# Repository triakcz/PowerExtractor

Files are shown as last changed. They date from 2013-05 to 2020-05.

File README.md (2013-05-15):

PowerExtractor
==============

GPL MPPT Regulator for bike (development prototype)

This is not finished project in development. Using Arduino to maximize power extracted from dynamo hub or solar panels ... yes it is so universal. Prototype tests shown power output of 8Watts @ 40km/h. Conversion efficiency is about 90% measured after initial rectification).

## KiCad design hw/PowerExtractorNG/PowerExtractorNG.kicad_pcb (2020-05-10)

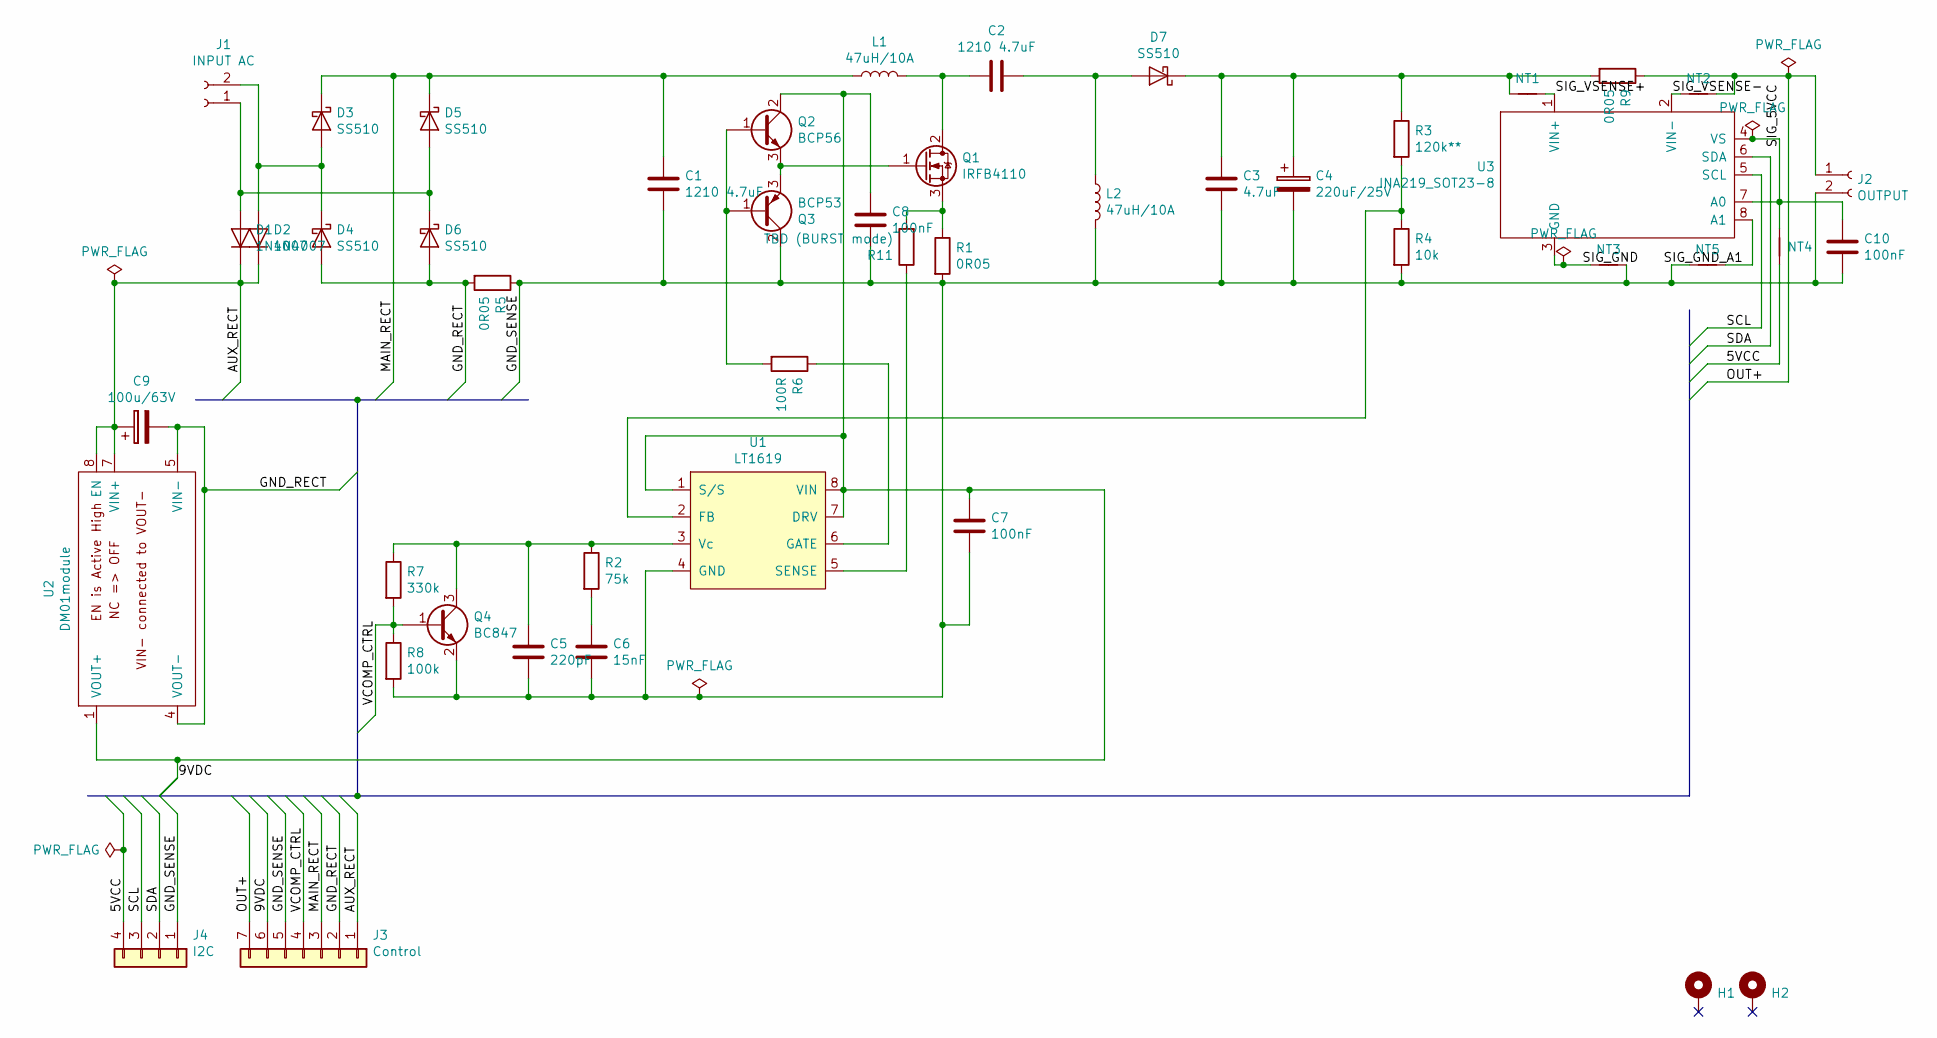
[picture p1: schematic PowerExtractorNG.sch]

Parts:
C1, C2: 1210 4.7uF; C_1210_3225Metric_Pad1.42x2.65mm_HandSolder
C3: 4.7uF; C_1210_3225Metric_Pad1.42x2.65mm_HandSolder
C4: 220uF/25V; CP_Radial_D10.0mm_P5.00mm
C5: 220pF; C_1206_3216Metric_Pad1.42x1.75mm_HandSolder
C6: 15nF; C_1206_3216Metric_Pad1.42x1.75mm_HandSolder
C7, C8, C10: 100nF; C_1206_3216Metric_Pad1.42x1.75mm_HandSolder
C9: 100u/63V; CP_Radial_D10.0mm_P5.00mm
D1, D2: 1N4007; D_SMA
D3, D4, D5, D6, D7: SS510; D_SMC_Handsoldering
H1, H2: MountingHole_Pad; MountingHole_3.2mm_M3_Pad
J1: INPUT AC; TerminalBlock_Altech_AK300-2_P5.00mm
J2: OUTPUT; TerminalBlock_Altech_AK300-2_P5.00mm
J3: Control; PinHeader_1x07_P2.54mm_Vertical
J4: I2C; PinHeader_1x04_P2.54mm_Vertical
L1, L2: 47uH/10A; L_Toroid_Vertical_L24.6mm_W15.5mm_P11.44mm_Pulse_KM-4
NT1, NT2, NT3, NT4, NT5: Net-Tie_2; NetTie-2_SMD_Pad0.5mm
Q1: IRFB4110; TO-220-3_Vertical
Q2: BCP56; SOT-223-3_TabPin2
Q3: BCP53; SOT-223-3_TabPin2
Q4: BC847; SOT-23
R1, R5, R9: 0R05; R_2512_6332Metric_Pad1.52x3.35mm_HandSolder
R2: 75k; R_1206_3216Metric_Pad1.42x1.75mm_HandSolder
R3: 120k**; R_1206_3216Metric_Pad1.42x1.75mm_HandSolder
R4: 10k; R_1206_3216Metric_Pad1.42x1.75mm_HandSolder
R6: 100R; R_1206_3216Metric_Pad1.42x1.75mm_HandSolder
R7: 330k; R_1206_3216Metric_Pad1.42x1.75mm_HandSolder
R8: 100k; R_1206_3216Metric_Pad1.42x1.75mm_HandSolder
R11: TBD (BURST mode); R_1206_3216Metric_Pad1.42x1.75mm_HandSolder
U1: LT1619; SO-8_5.3x6.2mm_P1.27mm
U2: DM01module; DM01_mod_THT
U3: INA219_SOT23-8; SOT-23-8_Handsoldering

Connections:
/5VCC: J4.4, NT4.2
/9VDC: C7.1, C8.1, J3.6, Q2.2 (C), U1.1 (S/S), U1.7 (DRV), U1.8 (VIN), U2.1 (VOUT+)
/AUX_RECT: C9.1, D1.1 (K), D2.1 (K), J3.1, U2.7 (VIN+), U2.8 (EN)
/GND_RECT: C9.2, D4.2 (A), D6.2 (A), J3.2, R5.2, U2.4 (VOUT-), U2.5 (VIN-)
/GND_SENSE: C1.2, C3.2, C4.2, C5.2, C6.2, C7.2, C8.2, C10.2, J2.2, J3.5, J4.1, L2.2, NT3.2, NT5.1, Q3.2 (C), Q4.2 (E), R1.2, R4.2, R5.1, R8.2, U1.4 (GND)
/MAIN_RECT: C1.1, D3.1 (K), D5.1 (K), J3.3, L1.1
/OUT+: J2.1, J3.7, NT2.2, R9.1
/SCL: J4.3, U3.5 (SCL)
/SDA: J4.2, U3.6 (SDA)
/SIG_5VCC: C10.1, NT4.1, U3.4 (VS), U3.7 (A0)
/SIG_GND: NT3.1, U3.3 (GND)
/SIG_GND_A1: NT5.2, U3.8 (A1)
/SIG_VSENSE+: NT1.2, U3.1 (VIN+)
/SIG_VSENSE-: NT2.1, U3.2 (VIN-)
/VCOMP_CTRL: J3.4, Q4.1 (B), R7.2, R8.1
unnamed: C2.1, D7.2 (A), L2.1
unnamed: C2.2, L1.2, Q1.2 (D)
unnamed: C3.1, C4.1, D7.1 (K), NT1.1, R3.1, R9.2
unnamed: C5.1, Q4.3 (C), R2.1, R7.1, U1.3 (Vc)
unnamed: C6.1, R2.2
unnamed: D1.2 (A), D5.2 (A), D6.1 (K), J1.1
unnamed: D2.2 (A), D3.2 (A), D4.1 (K), J1.2
unnamed: Q1.1 (G), Q2.3 (E), Q3.3 (E)
unnamed: Q1.3 (S), R1.1, R11.2
unnamed: Q2.1 (B), Q3.1 (B), R6.2
unnamed: R3.2, R4.1, U1.2 (FB)
unnamed: R6.1, U1.6 (GATE)
unnamed: R11.1, U1.5 (SENSE)

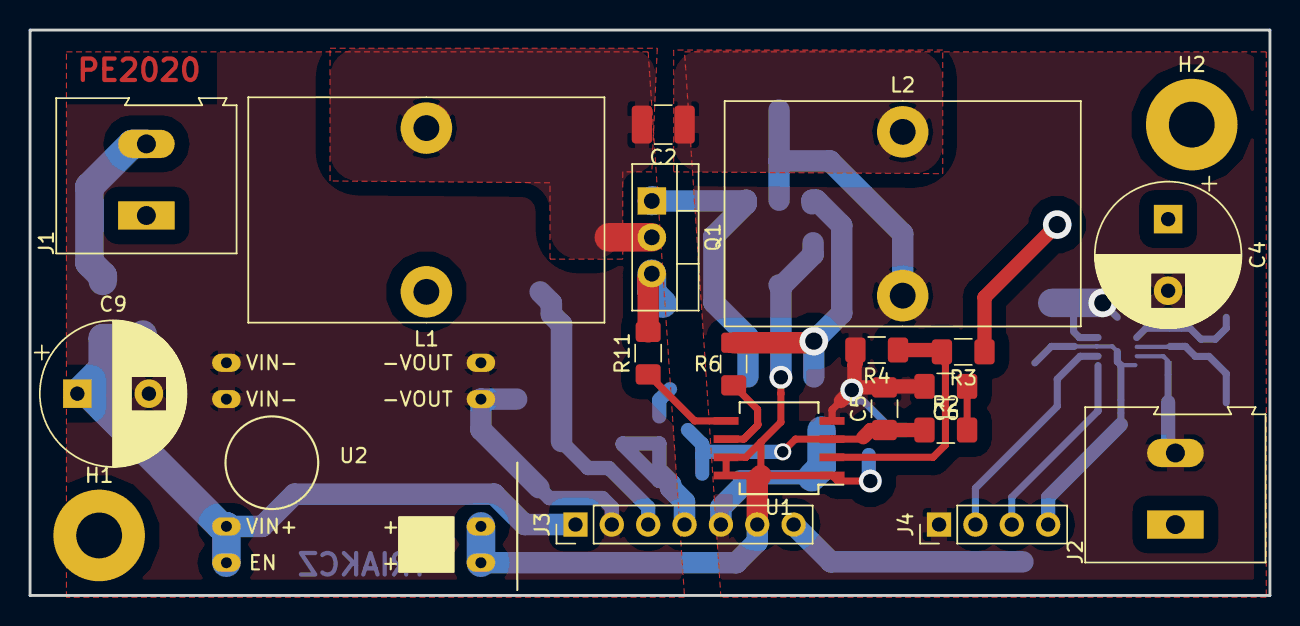
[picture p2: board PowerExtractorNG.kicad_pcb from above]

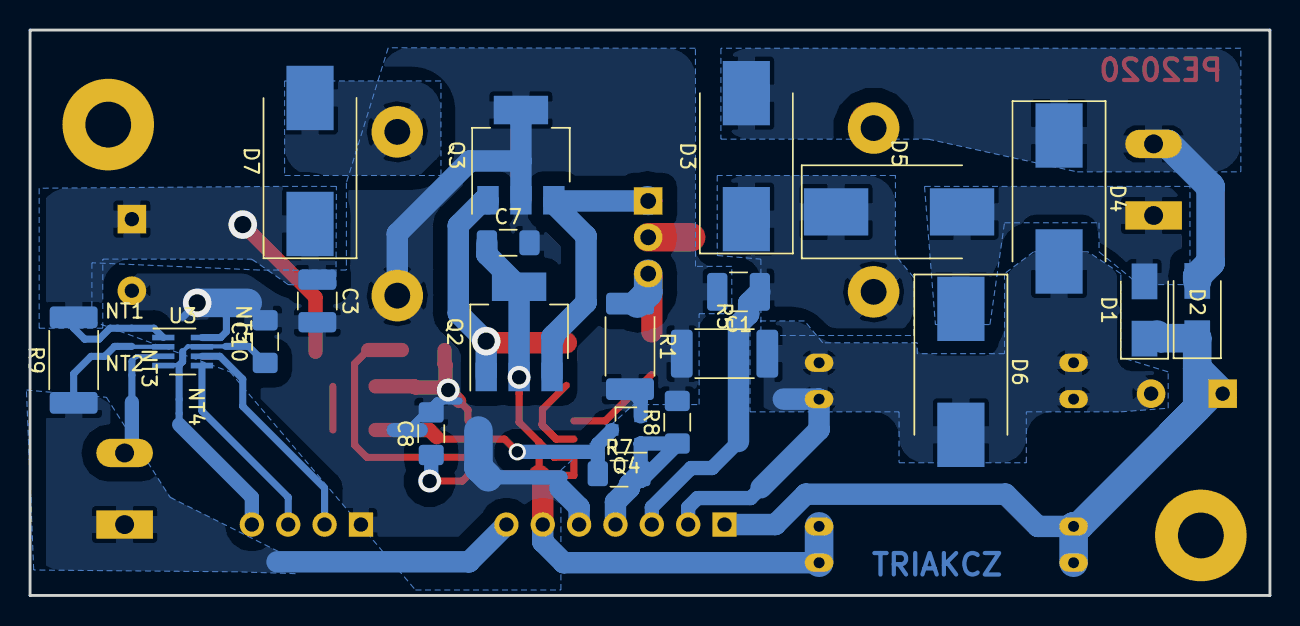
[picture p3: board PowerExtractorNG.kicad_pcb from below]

Board: 2 copper layers, 86.6 x 39.5 mm, 47 parts (26 on the bottom side), 28 nets.

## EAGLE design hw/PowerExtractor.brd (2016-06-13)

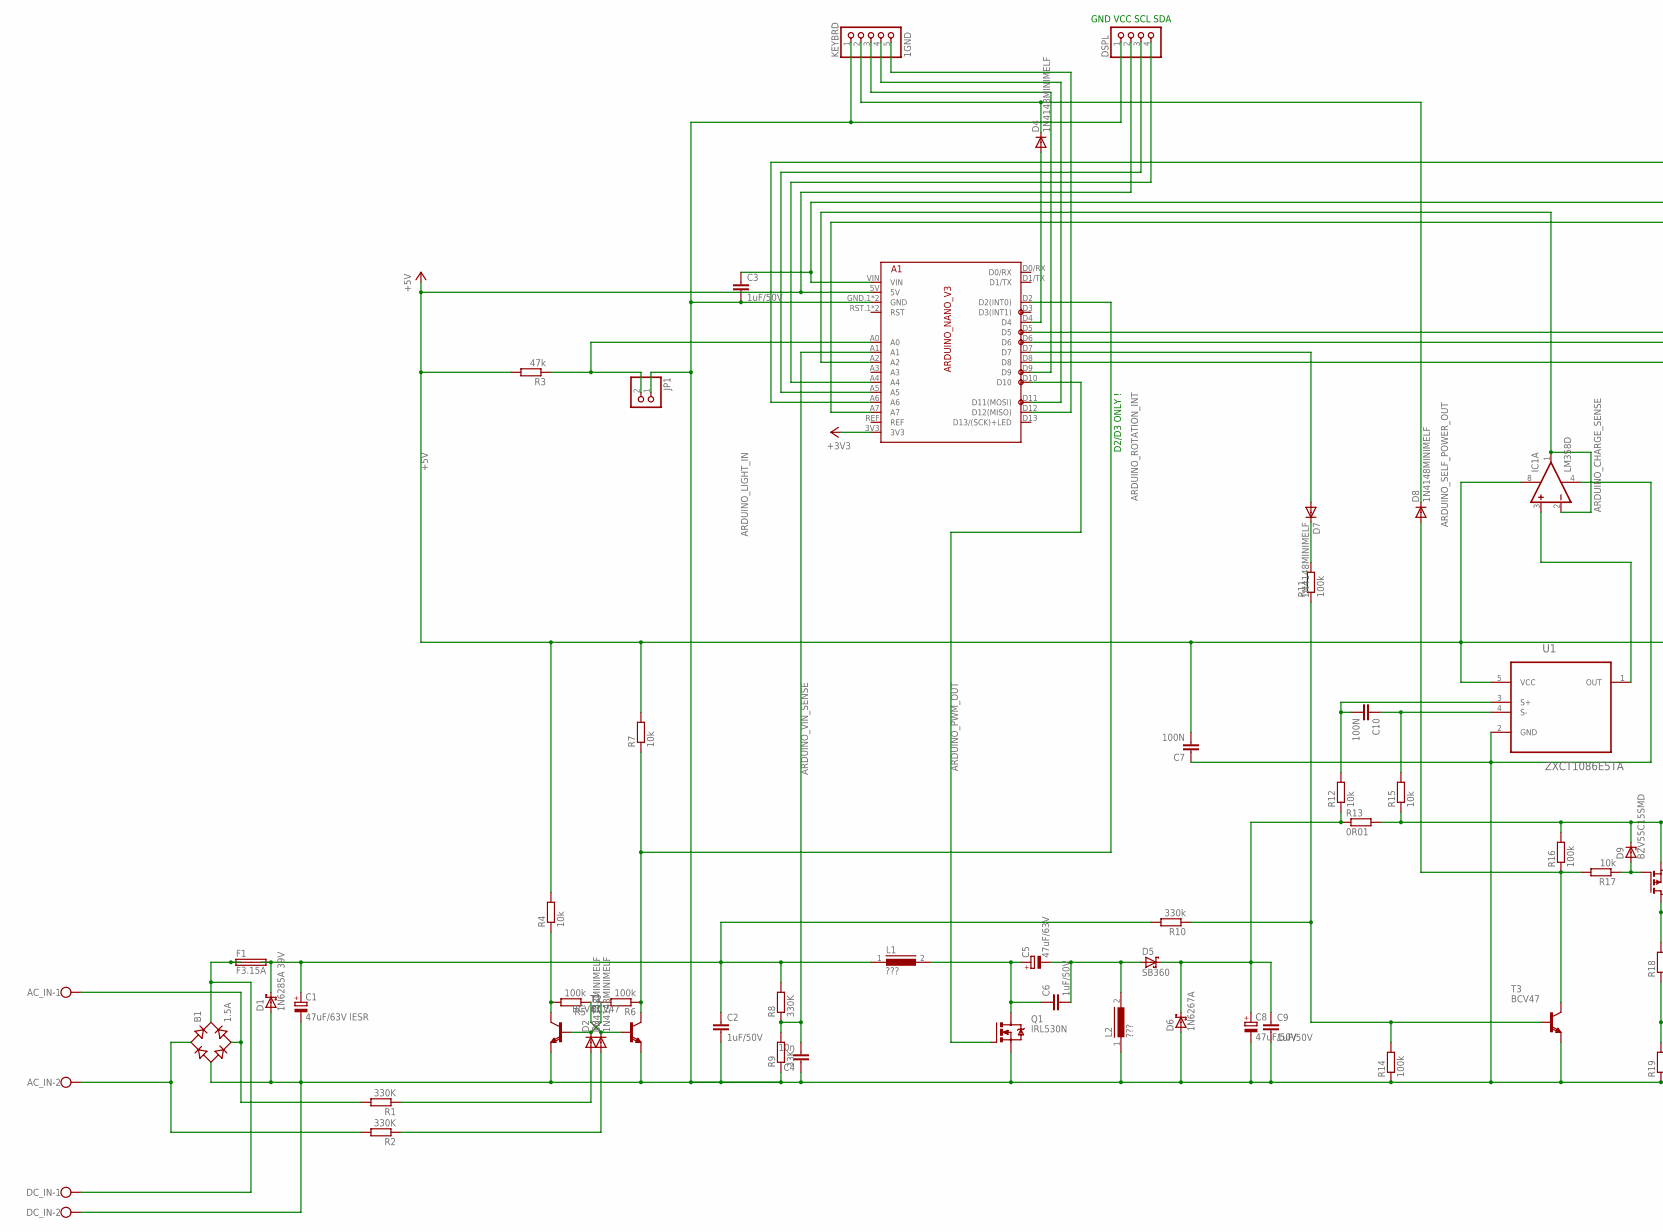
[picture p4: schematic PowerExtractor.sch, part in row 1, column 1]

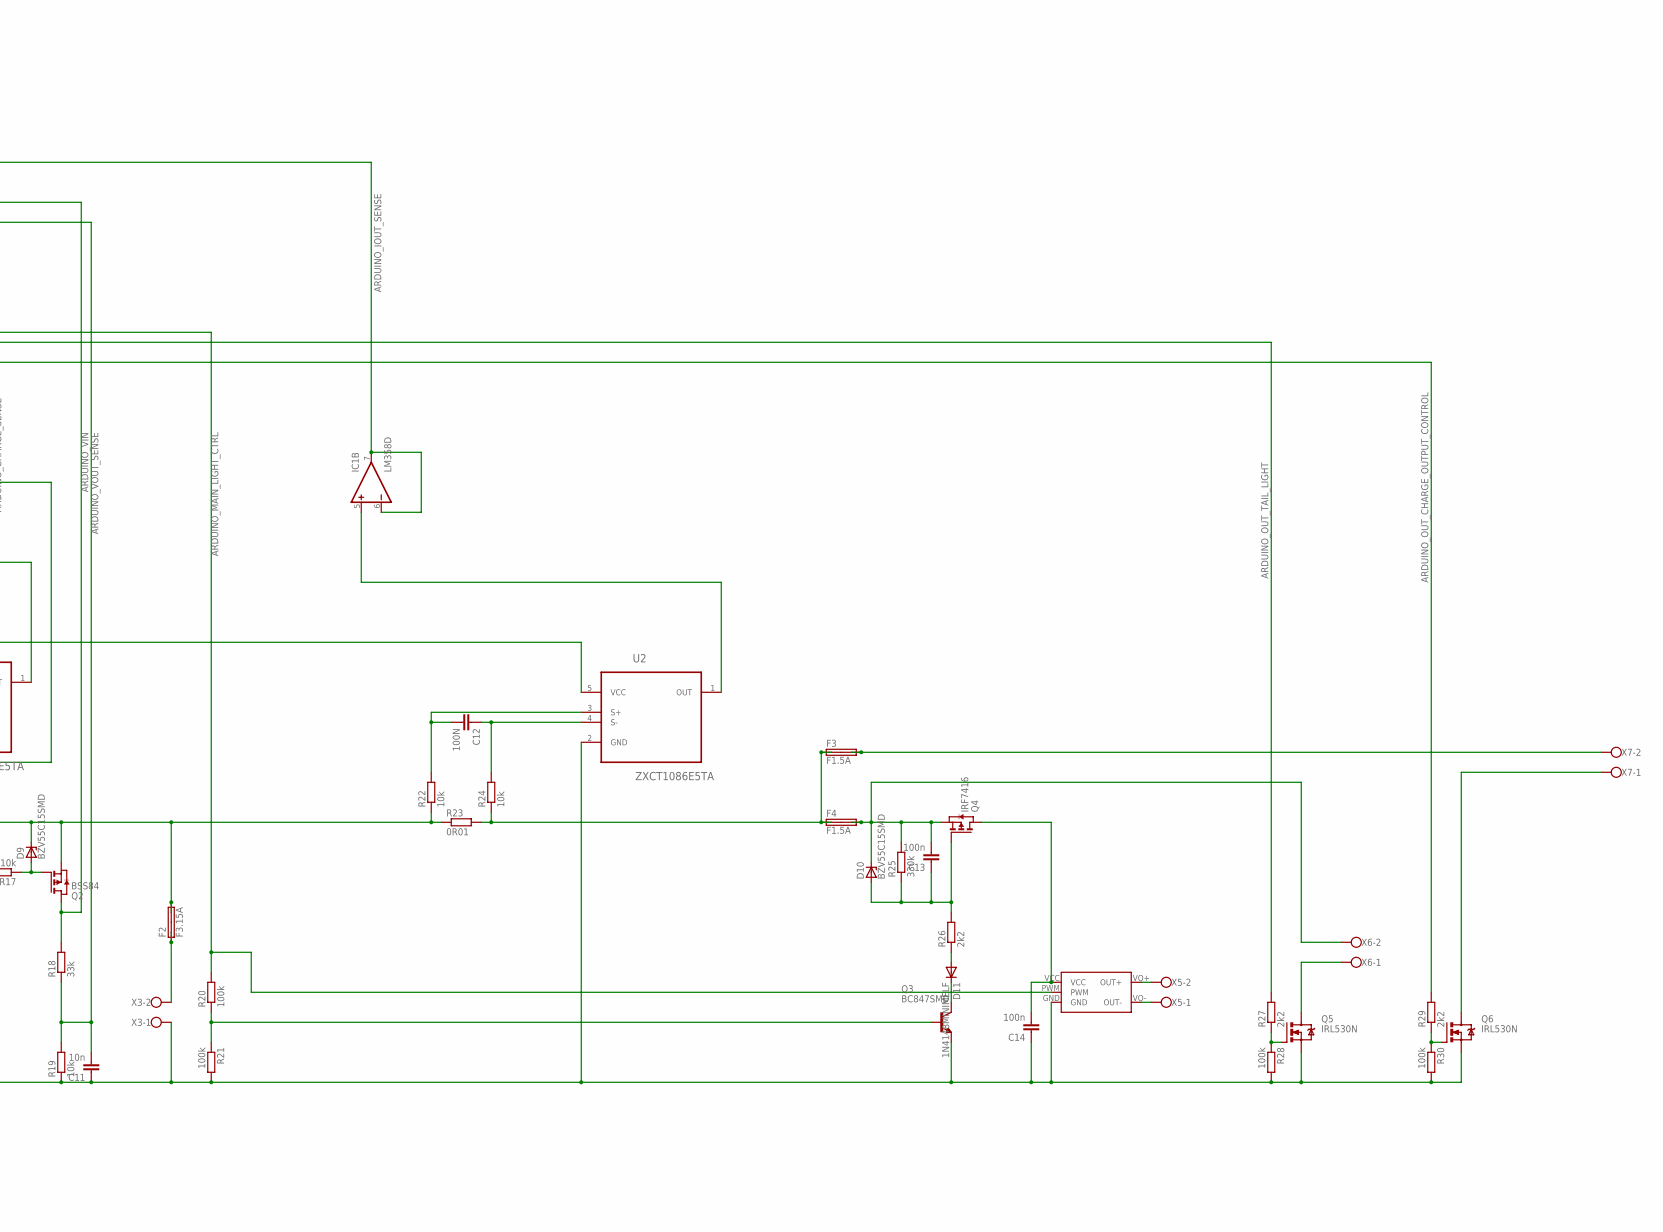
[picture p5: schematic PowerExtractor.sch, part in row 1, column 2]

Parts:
A1: ARDUINO_NANO_V3
AC_IN: W237-102
B1: 1.5A; RB1A
C1: 47uF/63V lESR; E5-8,5
C2, C3, C6, C9: 1uF/50V; C0805
C4, C11: 10n; C0805
C5: 47uF/63V; E5-8,5
C7, C10, C12: 100N; C0805
C8: 47uF/50V; E5-8,5
C13, C14: 100n; C0805
D1: 1N6285A 39V; C4111-15
D2, D3, D4, D7, D8, D11: 1N4148MINIMELF; SOD80C
D5: SB360; C4111-15
D6: 1N6267A; C4111-15
D9, D10: BZV55C15SMD; SOD80C
DC_IN: W237-102
DSPL: PINHD-1X4; 1X04
F1, F2: F3.15A; SHK20L
F3, F4: F1.5A; SHK20L
IC1: LM358D; SO08
JP1: PINHD-1X2; 1X02
KEYBRD: 1GND; 1X05
L1, L2: ???; SFT1030
Q1, Q5, Q6: IRL530N; TO220BV
Q2: BSS84; SOT23
Q3: BC847SMD; SOT23
Q4: IRF7416; SO-8
R1, R2, R8: 330K; M0805
R3: 47k; 0207/10
R4, R12, R15, R17, R19, R22, R24: 10k; M0805
R5, R20: 100k; 0207/10
R6, R30: 100k; R0805
R7: 10k; R0805
R9: 33K; R0805
R10: 330k; R0805
R11, R14, R16, R21, R28: 100k; M0805
R13, R23: 0R01; M1206
R18: 33k; M0805
R25: 330k; M0805
R26: 2k2; M0805
R27, R29: 2k2; 0207/10
T1, T2, T3: BCV47; SOT23
U1, U2: ZXCT1086E5TA; SOT95P280X130-5N
X3, X5, X6, X7: W237-102
X4: LDD700L; LDD_700L

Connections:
+3V3: A1.3V3
+5V: A1.5V, C7.2, DSPL.2, IC1.8 (V+), R3.2, R4.2, R7.2, U1.5 (VCC), U2.5 (VCC)
+OUT: F3.2A, F3.2B, X7.2
ARDUINO_CHARGE_SENSE: A1.A2, IC1.1 (OUT), IC1.2 (-IN)
ARDUINO_IOUT_SENSE: A1.A6, IC1.6 (-IN), IC1.7 (OUT)
ARDUINO_LIGHT_IN: A1.A0, JP1.2, R3.1
ARDUINO_MAIN_LIGHT_CTRL: A1.D5, R20.2, X4.PWM
ARDUINO_OUT_CHARGE_OUTPUT_CONTROL: A1.D8, R29.2
ARDUINO_OUT_TAIL_LIGHT: A1.D6, R27.2
ARDUINO_PWM_OUT: A1.D10, Q1.G
ARDUINO_ROTATION_INT: A1.D2 (D2(INT0)), R6.1, R7.1, T2.3 (C)
ARDUINO_SELF_POWER_OUT: A1.D7, D7.A
ARDUINO_VIN: A1.VIN, C3.1, Q2.3 (D), R18.2
ARDUINO_VIN_SENSE: A1.A1, C4.2, R8.1, R9.2
ARDUINO_VOUT_SENSE: A1.A7, C11.2, R18.1, R19.2
BAT+: F2.1A, F2.1B, X3.2
BAT+FUSED: D9.C, F2.2A, F2.2B, Q2.2 (S), R13.2, R15.1, R16.2, R22.1, R23.1
DISPLAY_SCL: A1.A5, DSPL.3
DISPLAY_SDA: A1.A4, DSPL.4
GND: A1.GND.1 (GND), A1.GND.2 (GND), B1.-, C1.-, C2.2, C3.2, C4.1, C7.1, C8.-, C9.2, C11.1, C14.1, D1.A, D6.A, DC_IN.2, DSPL.1, IC1.4 (V-), JP1.1, KEYBRD.1, L2.1, Q1.S, Q3.2 (E), Q5.S, Q6.S, R9.1, R14.1, R19.1, R21.2, R28.2, R30.2, T1.2 (E), T2.2 (E), T3.2 (E), U1.2 (GND), U2.2 (GND), X3.1, X4.GND
HUB1: AC_IN.1, B1.AC2, R1.2
HUB2: AC_IN.2, B1.AC1, R2.2
LIGHTVCC: C13.2, D10.C, F4.2A, F4.2B, Q4.1 (S), Q4.2 (S), Q4.3 (S), R25.2, X6.2
unnamed: C10.2, R12.2, U1.3 (S+)
unnamed: C5.+, C6.1, L1.2, Q1.D
unnamed: C5.-, C6.2, D5.A, L2.2
unnamed: R10.1, R11.1, R14.2, T3.1 (B)
unnamed: IC1.3 (+IN), U1.1 (OUT)
unnamed: D4.C, D8.C, KEYBRD.2
unnamed: D9.A, Q2.1 (G), R17.1
unnamed: IC1.5 (+IN), U2.1 (OUT)
unnamed: D11.C, Q3.3 (C)
unnamed: B1.+, DC_IN.1, F1.1A, F1.1B
unnamed: D7.C, R11.2
unnamed: X4.VO+ (OUT+), X5.2
unnamed: C13.1, D10.A, Q4.4 (G), R25.1, R26.2
unnamed: X4.VO- (OUT-), X5.1
unnamed: C10.1, R15.2, U1.4 (S-)
unnamed: Q3.1 (B), R20.1, R21.1
unnamed: D11.A, R26.1
unnamed: C14.2, Q4.5 (D), Q4.6 (D), Q4.7 (D), Q4.8 (D), X4.VCC
unnamed: D8.A, R16.1, R17.2, T3.3 (C)
unnamed: Q5.G, R27.1, R28.1
unnamed: Q5.D, X6.1
unnamed: A1.D9, KEYBRD.3
unnamed: Q6.G, R29.1, R30.1
unnamed: Q6.D, X7.1
unnamed: D2.A, R1.1
unnamed: R4.1, R5.2, T1.3 (C)
unnamed: D2.C, R6.2, T1.1 (B)
unnamed: D3.C, R5.1, T2.1 (B)
unnamed: A1.D11 (D11(MOSI)), KEYBRD.4
unnamed: D3.A, R2.1
unnamed: A1.D12 (D12(MISO)), KEYBRD.5
unnamed: A1.D4, D4.A
unnamed: C12.2, R22.2, U2.3 (S+)
unnamed: C12.1, R24.2, U2.4 (S-)
OUT+SENSED: F3.1A, F3.1B, F4.1A, F4.1B, R23.2, R24.1
OUTPUT_TO_SENSE: C8.+, C9.1, D5.C, D6.C, R12.1, R13.1
VIN: C1.+, C2.1, D1.C, F1.2A, F1.2B, L1.1, R8.2, R10.2

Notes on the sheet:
D2/D3 ONLY !
GND VCC SCL SDA

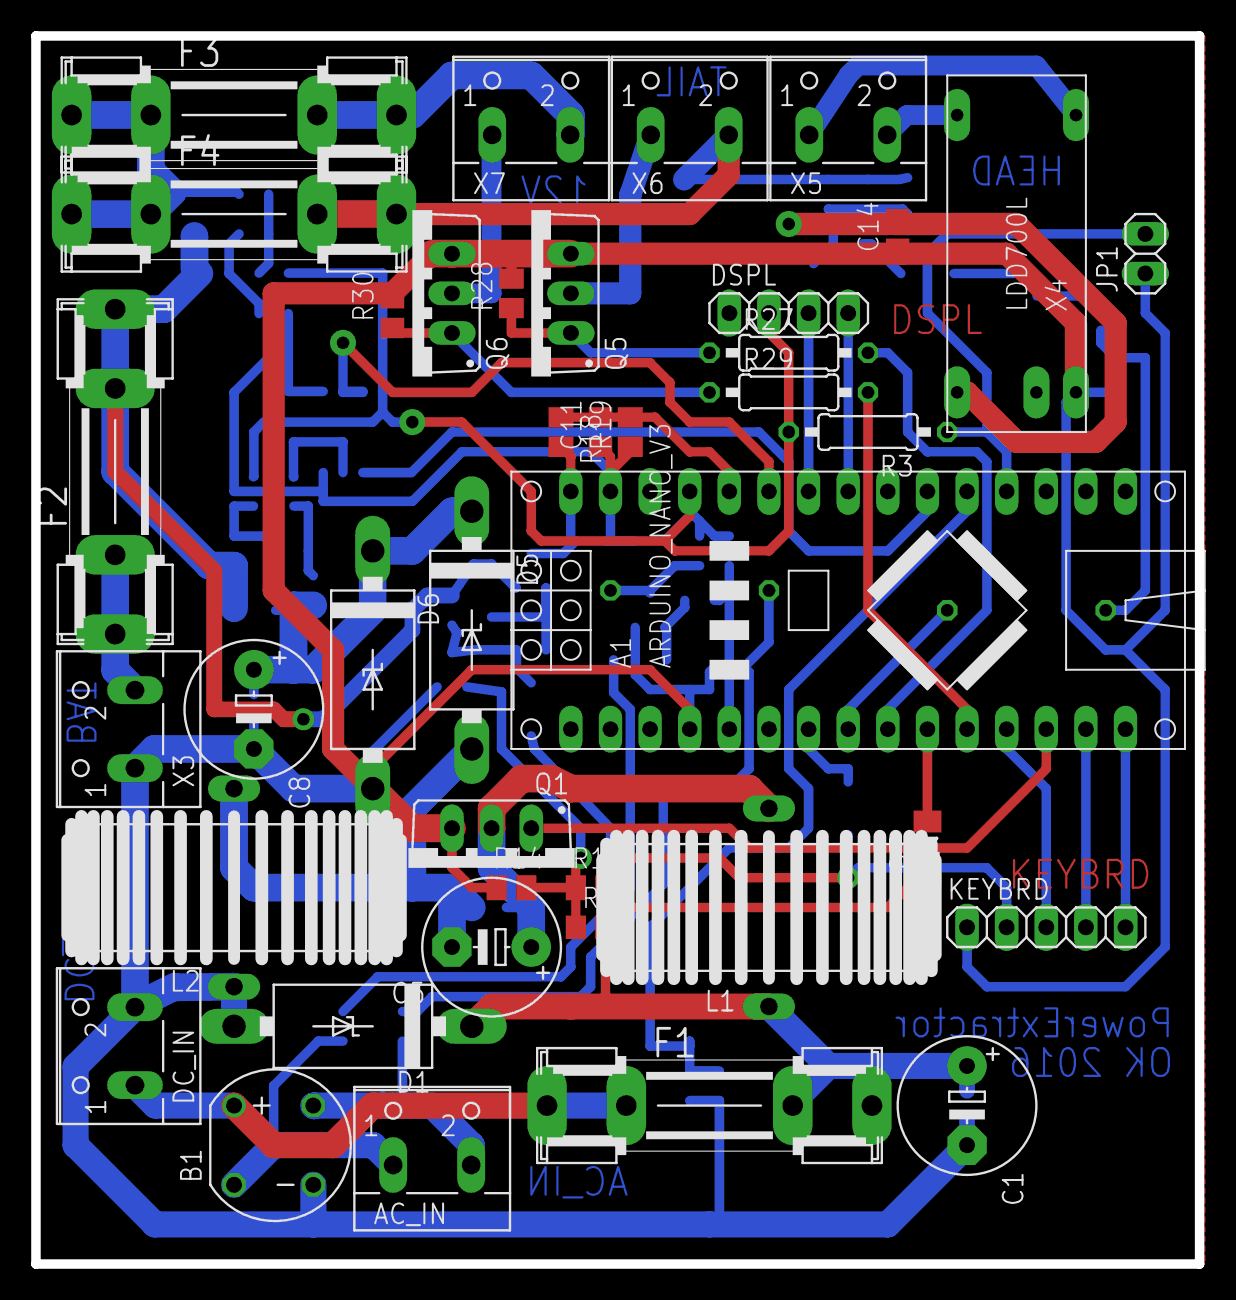
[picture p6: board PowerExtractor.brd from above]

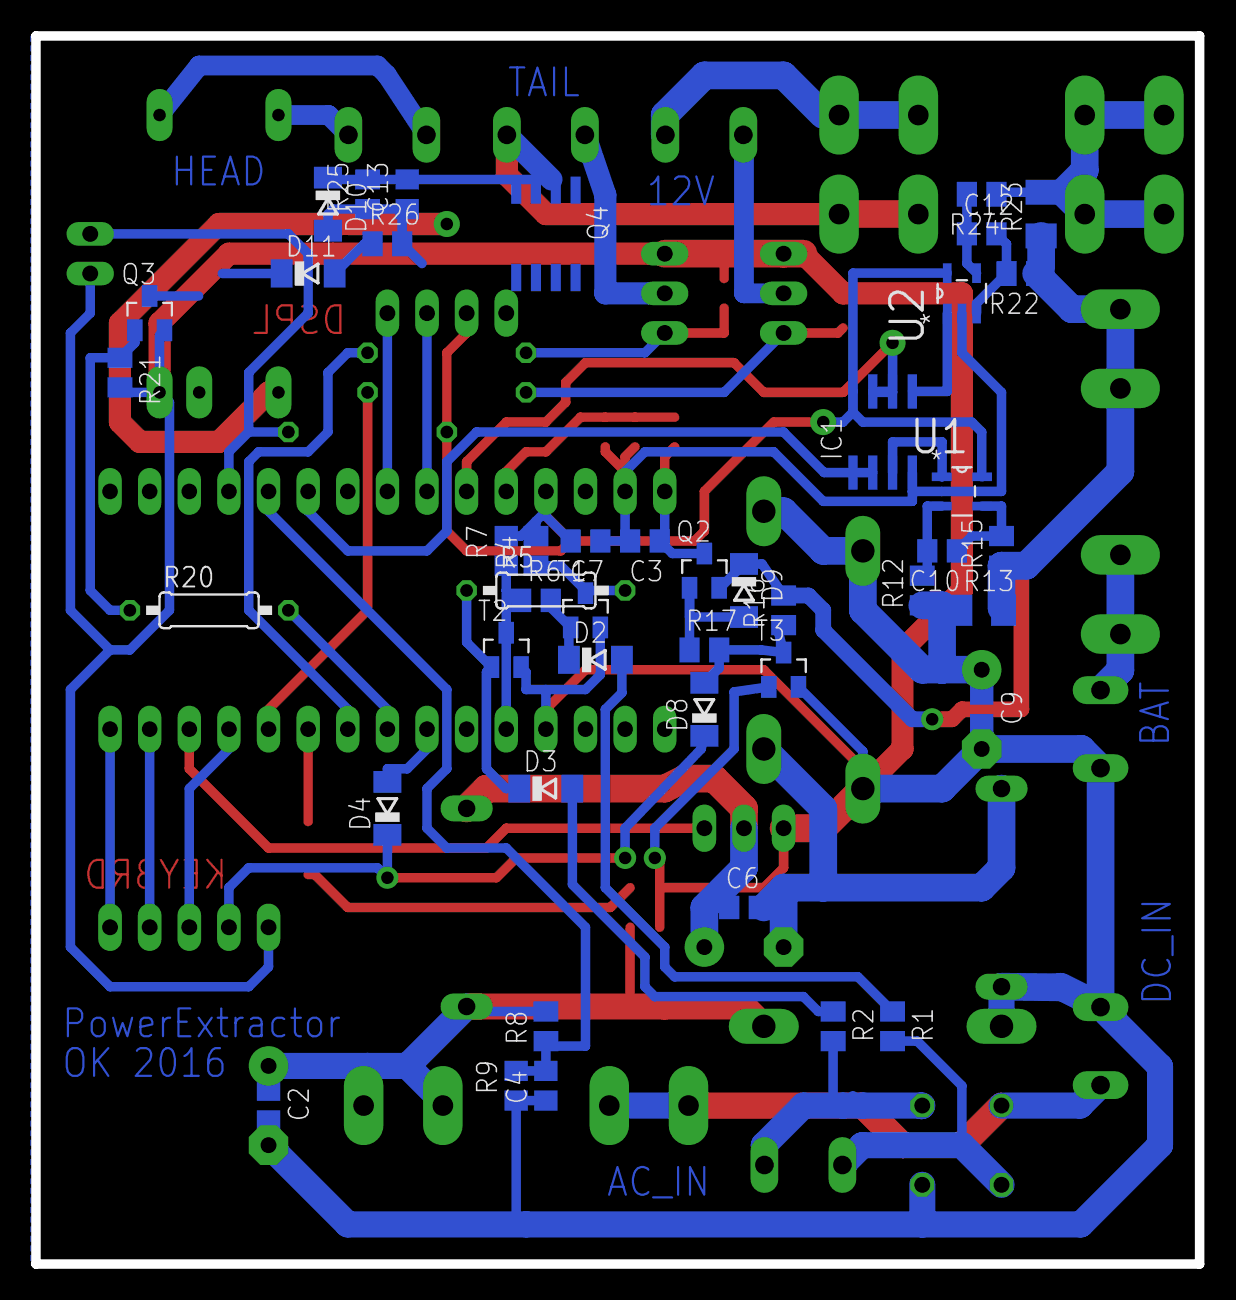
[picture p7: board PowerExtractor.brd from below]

Board: 2 copper layers, 74.6 x 78.7 mm, 85 parts (45 on the bottom side), 59 nets.

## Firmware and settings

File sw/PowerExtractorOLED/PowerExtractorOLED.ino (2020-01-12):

#include <SPI.h>
#include <Wire.h>
#include <Adafruit_GFX.h>
#include <Adafruit_SSD1306.h>
#include <avr/interrupt.h>

Adafruit_SSD1306 display(-1);

#define SELF_POWER 7
#define CHARGE_POWER 8
#define PWM_OUT 10
#define LED_FRONT 5
#define LED_TAIL 6
#define ROTATION_INPUT 2
#define SENSE_VI_CONV (5.*((330.+33)/33)/1024)
#define SENSE_VO_CONV (5.*((33.+10)/10)/1024)
#define SENSE_VI_UNIT "V"
#define SENSE_VO_UNIT "V"
#define SENSE_IO_CONV (((5/1024)/50)/0.01)
#define SENSE_II_CONV (((5./1024)/50)/0.01)
#define SENSE_IO_UNIT "A"
#define SENSE_II_UNIT "A"

#define SENSE_LIGHT 0
#define SENSE_II 2
#define SENSE_IO 6
#define SENSE_VI 1
#define SENSE_VO 7

#define ADC_MAX_SAMPLES 500

#define NUM_KEYS 4
const uint8_t KEYS[NUM_KEYS] = {9,4,12,11};

#define PWM_MAX 220

struct AdcOneValHolder {
  uint32_t value;
  uint16_t count;
};

struct AdcValuesHolder {
  uint16_t LIGHT;
  AdcOneValHolder VI;
  AdcOneValHolder VO;
  AdcOneValHolder II;
  AdcOneValHolder IO;
  boolean process;
};

struct AdcFilteredHolder {
  uint16_t light;
  uint16_t VI;
  uint16_t VO;
  uint16_t II;
  uint16_t IO;
};

volatile struct AdcValuesHolder adcvalues;
volatile struct AdcValuesHolder adcvalues2;
volatile struct AdcFilteredHolder adcfiltered;
uint16_t turnOffCounter=0xff;
uint8_t pwm=50;
volatile uint8_t pwm_front=0;

uint8_t blink;
volatile uint16_t rotations=0;

void rotation_interrupt() {
  rotations++;
  shiftAdcResult();
}

void setup() {
  display.begin(SSD1306_SWITCHCAPVCC, 0x3C);  // initialize with the I2C addr 0x3C (for the 128x64)
  display.clearDisplay();
  pinMode(13, OUTPUT);
  digitalWrite(13, HIGH);
  display.display();
  pinMode(SENSE_VI,INPUT);
  pinMode(SENSE_VO,INPUT);
  pinMode(SENSE_II,INPUT);
  pinMode(SENSE_IO,INPUT);
  pinMode(SELF_POWER,OUTPUT);
  pinMode(CHARGE_POWER,OUTPUT);
  digitalWrite(CHARGE_POWER,HIGH);
  digitalWrite(SELF_POWER,HIGH);
  pinMode(PWM_OUT,OUTPUT);
  pinMode(LED_TAIL,OUTPUT);
  pinMode(LED_FRONT,OUTPUT);
  digitalWrite(PWM_OUT,LOW);
  for (uint8_t i=0;i<NUM_KEYS;i++) {
    pinMode(KEYS[i], INPUT_PULLUP);
  }
  // http://playground.arduino.cc/Main/TimerPWMCheatsheet
  TCCR1B = (TCCR1B & 0b11111000) | 0x01;
  
  pinMode(ROTATION_INPUT, INPUT);
  attachInterrupt(0, rotation_interrupt, RISING);
  
  // Setup timer2 for interrupt
  TIMSK2 |= (1 << TOIE2);
  TCCR2B = TCCR2B & 0b11111000 | 0x07;
  ADCSRA = 0;
  ADCSRB = 0;
  ADMUX |= (1 << REFS0); //set reference voltage
  ADCSRA |= (1 << ADPS2) | (1 << ADPS0); //ADC CLK 16mHz/32/13 ... cca 38kHz
  ADCSRA |= (1 << ADATE); //free running mode (not setting any ADTS bits)
  ADCSRA |= (1 << ADIE); //enable interrupts when measurement complete
  ADCSRA |= (1 << ADEN); //enable ADC
  ADCSRA |= (1 << ADSC); //start ADC measurements
}

volatile uint16_t timercnt=0;

ISR(TIMER2_OVF_vect) {
  timercnt++;  
  blink++;
  if (blink==14 && pwm_front > 0) {
    digitalWrite(LED_TAIL,HIGH);
  } else if (blink == 16) {
    digitalWrite(LED_TAIL,LOW);
    blink=0;
  }     
}

uint8_t adcidx=SENSE_LIGHT;

void shiftAdcResult() {
  cli();
  adcvalues2.VI.value=adcvalues.VI.value;
  adcvalues2.VI.count=adcvalues.VI.count;
  adcvalues2.VO.value=adcvalues.VO.value;
  adcvalues2.VO.count=adcvalues.VO.count;
  adcvalues2.II.value=adcvalues.II.value;
  adcvalues2.II.count=adcvalues.II.count;
  adcvalues2.IO.value=adcvalues.IO.value;
  adcvalues2.IO.count=adcvalues.IO.count;
  adcvalues2.LIGHT=adcvalues.LIGHT;
  adcvalues2.process=true;
  adcvalues.VI.value=0;
  adcvalues.VI.count=0;
  adcvalues.II.value=0;
  adcvalues.II.count=0;
  adcvalues.VO.value=0;
  adcvalues.VO.count=0;
  adcvalues.IO.value=0;
  adcvalues.IO.count=0;
  adcvalues.LIGHT=0;
  adcvalues.process=false;
  sei();
}

ISR(ADC_vect) {
  uint8_t low = ADCL;
  uint8_t high = ADCH;
  uint16_t val = (high << 8) | low;
  ADMUX&=~(0x07);
  switch (adcidx) {
    case SENSE_LIGHT:
      ADMUX|=SENSE_II;
      adcvalues.LIGHT=val;
      if (adcvalues.VO.count > ADC_MAX_SAMPLES || adcvalues.process) {
        shiftAdcResult();
      }
      break;
    case SENSE_II:
      ADMUX|=SENSE_IO;
      adcvalues.II.value+=val;
      adcvalues.II.count++;
      if (adcvalues.VO.count > ADC_MAX_SAMPLES || adcvalues.process) {
        shiftAdcResult();
      }
      break;
    case SENSE_IO:
      ADMUX|=SENSE_VI;
      adcvalues.IO.value+=val;
      adcvalues.IO.count++;
      if (adcvalues.VO.count > ADC_MAX_SAMPLES || adcvalues.process) {
        shiftAdcResult();
      }
      break;
    case SENSE_VI:
      ADMUX|=SENSE_VO;
      adcvalues.VI.value+=val;
      adcvalues.VI.count++;
      if (adcvalues.VI.count > ADC_MAX_SAMPLES || adcvalues.process) {
        shiftAdcResult();
      }
      break;
    case SENSE_VO:
      ADMUX|=SENSE_LIGHT;
      adcvalues.VO.value+=val;
      adcvalues.VO.count++;
      if (adcvalues.VO.count > ADC_MAX_SAMPLES || adcvalues.process) {
        shiftAdcResult();
      }
      break;
  }
  adcidx=(ADMUX&0x07);
}

int i;

#define CHAR_X_SIZE 6
#define CHAR_Y_SIZE 7
#define KMH_SIZE 9
#define KMH_L_SIZE 3

#define BAT_X1 2*KMH_SIZE*CHAR_X_SIZE+1
#define BAT_Y1 5
#define BAT_W 18
#define BAT_H 32

void displaykmh(int value) {
  byte posx=0;
  if (value < 100) {
    posx=KMH_SIZE*CHAR_X_SIZE;
  }
  display.setCursor(posx,0);  
  display.setTextSize(KMH_SIZE);
  display.setTextColor(WHITE);
  display.println(i/10);
  display.setTextSize(KMH_L_SIZE);
  display.setCursor(2*KMH_SIZE*CHAR_X_SIZE,CHAR_Y_SIZE * (KMH_SIZE - KMH_L_SIZE));
  display.println(i%10);
}

void displayBatSymbol(byte chargeLevel) {
  if (chargeLevel > 10) {
    chargeLevel=10;
  }
  display.drawRect(BAT_X1, BAT_Y1, BAT_W, BAT_H, WHITE);
  display.fillRect(BAT_X1+BAT_W/3, BAT_Y1-(BAT_H/10), BAT_W/3, (BAT_H/10), WHITE);
  display.fillRect(BAT_X1, BAT_Y1+((BAT_H*(10-chargeLevel))/10), BAT_W, BAT_H-((BAT_H*(10-chargeLevel))/10), WHITE);
}

#define str(x) #x
#define dispADVal(TYPE) {\
  display.print(str(TYPE) "= ");\
  display.print(adcfiltered.TYPE * SENSE_##TYPE##_CONV );\
  display.print(SENSE_##TYPE##_UNIT);\
}

byte keyState=0xff;

byte handleKbd() {
  for (uint8_t i=0;i<NUM_KEYS;i++) {
    if (!digitalRead(KEYS[i])) {
      if (keyState & 1<<i ) {
        keyState &= ~(1<<i);
        return i+1;
      }
    } else {
      keyState |= 1<<i;
    }
  }
  return 0;
}

void loop() {
  boolean blink;
  if (blink) {
    digitalWrite(13, HIGH);
  } else { 
    digitalWrite(13,LOW);
  }
  blink = !blink;
  if (adcvalues2.process) {
    adcfiltered.VI=adcvalues2.VI.value/adcvalues2.VI.count;
    adcfiltered.VO=adcvalues2.VO.value/adcvalues2.VO.count;
    adcfiltered.II=adcvalues2.II.value/adcvalues2.II.count;
    adcfiltered.IO=adcvalues2.IO.value/adcvalues2.IO.count;
    adcvalues2.process=false;
  }
  display.clearDisplay();
  display.setTextColor(WHITE);
  display.setTextSize(2);
  display.setCursor(0,0);
//  display.print(adcvalues.VO);
  dispADVal(VO);
  display.println();
//  display.print(adcvalues.VI);
  dispADVal(VI);
  display.println();
//  display.print(adcvalues.IO);
  dispADVal(IO);
  display.println();
//  display.print(adcvalues.II);
  dispADVal(II);
  display.println();
  display.display();  
  switch (handleKbd()) {
    case 1:    
      pwm_front+=32;
      break;
    case 2:
      if (pwm_front>0) pwm_front-=32;
      break;
    case 3:
      pwm+=10;
      break;
    case 4:
      pwm-=10;
      break;
  }
  analogWrite(PWM_OUT,pwm);
  analogWrite(LED_FRONT,pwm_front);
  
  if (pwm_front > 0) {
    turnOffCounter=0xff;
  }
  if (turnOffCounter>0) {
    turnOffCounter--;
    digitalWrite(SELF_POWER,HIGH);
  } else {
    digitalWrite(SELF_POWER,LOW);    
  }
}

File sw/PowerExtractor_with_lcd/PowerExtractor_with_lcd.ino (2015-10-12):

#include <avr/interrupt.h>
#include <avr/io.h>

#include <LiquidCrystal.h>
LiquidCrystal lcd(2, 4, 7, 8, 11, 12);

// voltage of one div of A/D (based on resistor divider) in Volts
#define VOLTAGE_IN_DIV (1.1/1024)*((220+4.7)/4.7)
#define VOLTAGE_OUT_DIV (1.1/1024)*((220+10)/10)

// current of one div of A/D (based on sensing resistor and sense amplifier) in Amperes per DIV
#define CURRENT_DIV (1.1/1024.0)/0.1
//#define CURRENT_DIV (50*0.03)/1024

// Target voltage: formula TARGET_VOLTAGE=7.2/VOLTAGE_OUT_DIV
#define TARGET_VOLTAGE 558

#define SELF_POWER 5

/* Maximum duty cycle, 100% is 255, we have SEPIC converter, so 100% duty cycle is nonsense to use, it will saturate coils and output
 voltage will be 0.
 */
#define MAX_PWM 200

byte pwm;
byte pwmp;
byte step;
byte key;
volatile int voltage;
volatile int vin;
float wh = 0;
volatile boolean whcount = false;
volatile boolean display_flag = false;
boolean whdisplay = false;
int whperiod = 0;
byte off_counter = 0;
int mppt_counter;
int measure_counter;
volatile int current;
boolean dir;
long lastpower;

#define VOUT_MPPT_RUNNING 0
#define VOUT_POWER_OK 1
#define VOUT_CRITICAL 2

volatile byte vout_flag;
int vout_flag_remove;

// called with frequency of 31,5kHz
ISR(TIMER2_OVF_vect) {
  measure_counter += 1;
  if (measure_counter == 200) {
    //reading twice to get more precise output after switching measurement MUX
    analogRead(A5);
    vin = analogRead(A5);
  } 
  else if ( measure_counter==400 ) {
    analogRead(A7);
    current = analogRead(A7);
  } 
  else if ( measure_counter==600 ) {
    analogRead(A6);
    voltage = analogRead(A6);
    if (voltage > TARGET_VOLTAGE) {
      pwm--;
      if (voltage > (TARGET_VOLTAGE * 1.05)) {
        vout_flag = VOUT_CRITICAL;
        vout_flag_remove = 15000;
        step = step * 2;
        if (step > 16) {
          step = 16;
        }
        pwm -= step;
      }

      dir = false;
      if (vout_flag == VOUT_MPPT_RUNNING ) {
        vout_flag = VOUT_POWER_OK;
        vout_flag_remove = 5000;
        pwmp=20;
      }
    } 
    else if (vout_flag == VOUT_POWER_OK) {
      if (voltage>TARGET_VOLTAGE*0.99) {
        vout_flag_remove = 5000;
      }
      if (pwmp==0) {
        pwm++;
        pwmp=10;
      } 
      else {
        pwmp--;
      }
    }
    analogWrite(3, pwm);
    measure_counter=0;
    mppt_counter+=1;
    if (mppt_counter >= 20) {
      mppt_counter = 0;
      if (vout_flag == VOUT_MPPT_RUNNING) mppt_do();
        if (current < 10) {
          off_counter+=1;
          if ( off_counter>= 99) {
            digitalWrite(SELF_POWER,LOW);
            off_counter=99;
          }
        } else {
          off_counter=0;
          digitalWrite(SELF_POWER,HIGH);
        }
        whcount = true;
        display_flag = true;
    }
  }
  if (vout_flag_remove != 0) {
    vout_flag_remove--;
  } 
  else if (vout_flag!=VOUT_MPPT_RUNNING) {
    step=1;
    dir=-1;
    vout_flag = VOUT_MPPT_RUNNING;         
  }
};

void setup()
{
  analogReference(INTERNAL);
  // Enable interrupt from timer2
  TIMSK2 |= (1 << TOIE2);
  // set up the LCD's number of columns and rows:
  TCCR2B = TCCR2B & 0b11111000 | 0b00000001;
  pwm = 40;
  voltage = 0;
  dir = true;
  step = 1;
  lastpower = 0;
  createChars();
  lcd.begin(16, 2);
  pinMode(2,OUTPUT);
  pinMode(SELF_POWER,OUTPUT);
  digitalWrite(SELF_POWER,HIGH);
  pinMode(A7,INPUT);
  digitalWrite(2,HIGH);
}

void createChars()
{
  byte newChar[8];

  for (byte c = 0; c < 8; c++) {
    for (byte i = 0; i < 8; i++) {
      if (dir) {
        if (i > c) {
          newChar[7 - i] = B10001;
        } 
        else {
          newChar[7 - i] = B11111;
        }
      }
    }
    lcd.createChar(c, newChar);
  }
}

void mppt_do()
{
  long power=(voltage*current);
  if (lastpower > power) {
    if (step > 2) {
      step /= 2;
    } 
    else {
      if (step > 1) {
        step = 1;
      }
    }
    dir = !dir;
  } 
  else {
    step++;
    if (step > 10) {
      step = 10;
    }
  }

  if (dir) {
    if (pwm + step < MAX_PWM) pwm += step;
    else {
      pwm = MAX_PWM;
      dir = false;
    }
  } 
  else {
    if (pwm - step > 0) pwm -= step;
    else {
      pwm = 0;
      dir = true;
    }
  }
  lastpower = power;
}

void loop()
{
  if (whcount) addWh();
  if (display_flag) updateDisplay();
}

void updateDisplay() {
  display_flag=false;
  //line 1
  lcd.setCursor(0, 0);
  switch (vout_flag) {
  case VOUT_POWER_OK:
    lcd.print("**");
    break;
  case VOUT_CRITICAL:
    lcd.print("!!");
    break;
  case VOUT_MPPT_RUNNING:
    // step direction
    if (dir) {
      lcd.print("^");
    } 
    else {
      lcd.print("v");
    }
    // step bargraph
    byte stepWrite = step - 1;
    if (stepWrite > 7) stepWrite = 7;
    lcd.write(stepWrite);  
  }
  // arrow
  lcd.write(byte(0x7e));
  // pwm bargraph
  lcd.write(byte(((pwm - 1) * 8) / 200));
  lcd.print(9-off_counter/10);
  lcd.print("    ");
  lcd.setCursor(8, 0);
  if (whdisplay) {
    lcd.print("Vi=");
    lcd.print(((5. * vin / 1024.) / 470.) * (4700. + 470.));
    lcd.print("V");
  } 
  else {
    lcd.print("Io=");
    lcd.print( current * CURRENT_DIV );
    lcd.print("A");
  }
  lcd.print(" ");
  lcd.setCursor(0, 1);
  whperiod++;
  if (whperiod > 30) {
    whdisplay = !whdisplay;
    whperiod = 0;
  }
  if (whdisplay) {
    int wprint = wh * 1000;
    lcd.print(wprint / 10000);
    wprint %= 10000;
    lcd.print(wprint / 1000);
    wprint %= 1000;
    lcd.print(".");
    lcd.print(wprint / 100);
    wprint %= 100;
    lcd.print(wprint / 10);
    wprint %= 10;
    lcd.print(wprint);
    lcd.print("Wh  ");
  } 
  else {
    lcd.print((current * CURRENT_DIV) * (voltage * VOLTAGE_OUT_DIV));
    lcd.print("W   ");
  }
  lcd.setCursor(8, 1);
  lcd.print("Vo=");
  lcd.print(voltage * VOLTAGE_OUT_DIV);
}

void addWh()
{  
  whcount = false;
  wh += (current * CURRENT_DIV * voltage * VOLTAGE_OUT_DIV) / (0.2625*3600);
}

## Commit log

2013-05-15 First version of prototype firmware
2013-05-15 First version of MPPT prototype
    [PowerExtractor.sch]
2013-05-16 Experimentally switching USB power output with NXP630AD2T by UP/DOWN keys
2015-06-21 Modifications of schematic and added library with components
    [PowerExtractor.sch]
2015-06-22 Add 5V USB out, 12V out, both controlled by arduino
    [PowerExtractor.sch]
2015-06-23 Arduino Nano V3 in library
    [PowerExtractor.sch]
2015-10-12 Connected arduino in schematic
    [PowerExtractor.sch]
2016-03-20 Adding latest version
    [PowerExtractor.brd, PowerExtractor.sch]
2016-03-20 Routing of board
    [PowerExtractor.brd, PowerExtractor.sch]
2016-03-21 Refactored layout
    [PowerExtractor.brd, PowerExtractor.sch]
2016-03-22 Completely routed
    [PowerExtractor.brd, PowerExtractor.sch]
2016-03-23 set reasonable width of power lines
    [PowerExtractor.brd]
2016-04-03 Added spice netlist for new speedsense circuit
2016-04-05 Fixed speed sense circuit
    [PowerExtractor.brd, PowerExtractor.sch]
2016-04-07 Shifted speed sense circuit under MCU
    [PowerExtractor.brd, PowerExtractor.sch]
2016-04-07 Refactored PCB layout
    [PowerExtractor.brd, PowerExtractor.sch]
2016-04-10 Added prefix to custom devices in eagle library
2016-04-10 Updated library - arduino removed holes from dimension layer
    [PowerExtractor.brd, PowerExtractor.sch]
2016-04-11 Fixed values and types of few parts
    [PowerExtractor.brd, PowerExtractor.sch]
2016-04-14 Fixed BSS84 pinout
    [PowerExtractor.brd, PowerExtractor.sch]
2016-04-21 Multiple firmware parts
    - Manual PWM control
    - Voltage read and display functions
    - Keyboard handling method
    - Added interrupts for periodic actions
    - Turnofftimer skeleton
2016-04-21 Fixed wrongly placed resistor (0207 placed on bottom side)
    [PowerExtractor.brd]
2016-06-12 Fixing various bugs
    [PowerExtractor.brd, PowerExtractor.sch]
2016-06-13 multiple fixes
    [PowerExtractor.brd, PowerExtractor.sch]
2020-01-12 backup all
    [PowerExtractorNG.kicad_pcb, PowerExtractorNG.sch]
2020-01-12 wip kicad
    [PowerExtractorNG.kicad_pcb, PowerExtractorNG.sch]
